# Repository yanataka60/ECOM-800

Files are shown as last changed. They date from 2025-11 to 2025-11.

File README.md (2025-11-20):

# ECOM-800

　トランジスタ技術 1977年10月号から1978年1月号にかけて連載されていた「マイコンピュータをつくろう(SC/MP編)」のECOM-800の基板を起こしました。

## 回路図
　KiCadフォルダ内のECOM-800.pdfを参照してください。

　掲載されている回路から以下の変更をしています。

　・ワンボードとするためにロータリースイッチをスライドスイッチに変更しています。

　・81LS95を74LS244に変更しています。

　・SRAMを6264としています。

　・SRAMのバッテリーバックアップを付加しました。

[回路図](https://github.com/yanataka60/ECOM-800/blob/main/Kicad/ECOM-800.pdf)
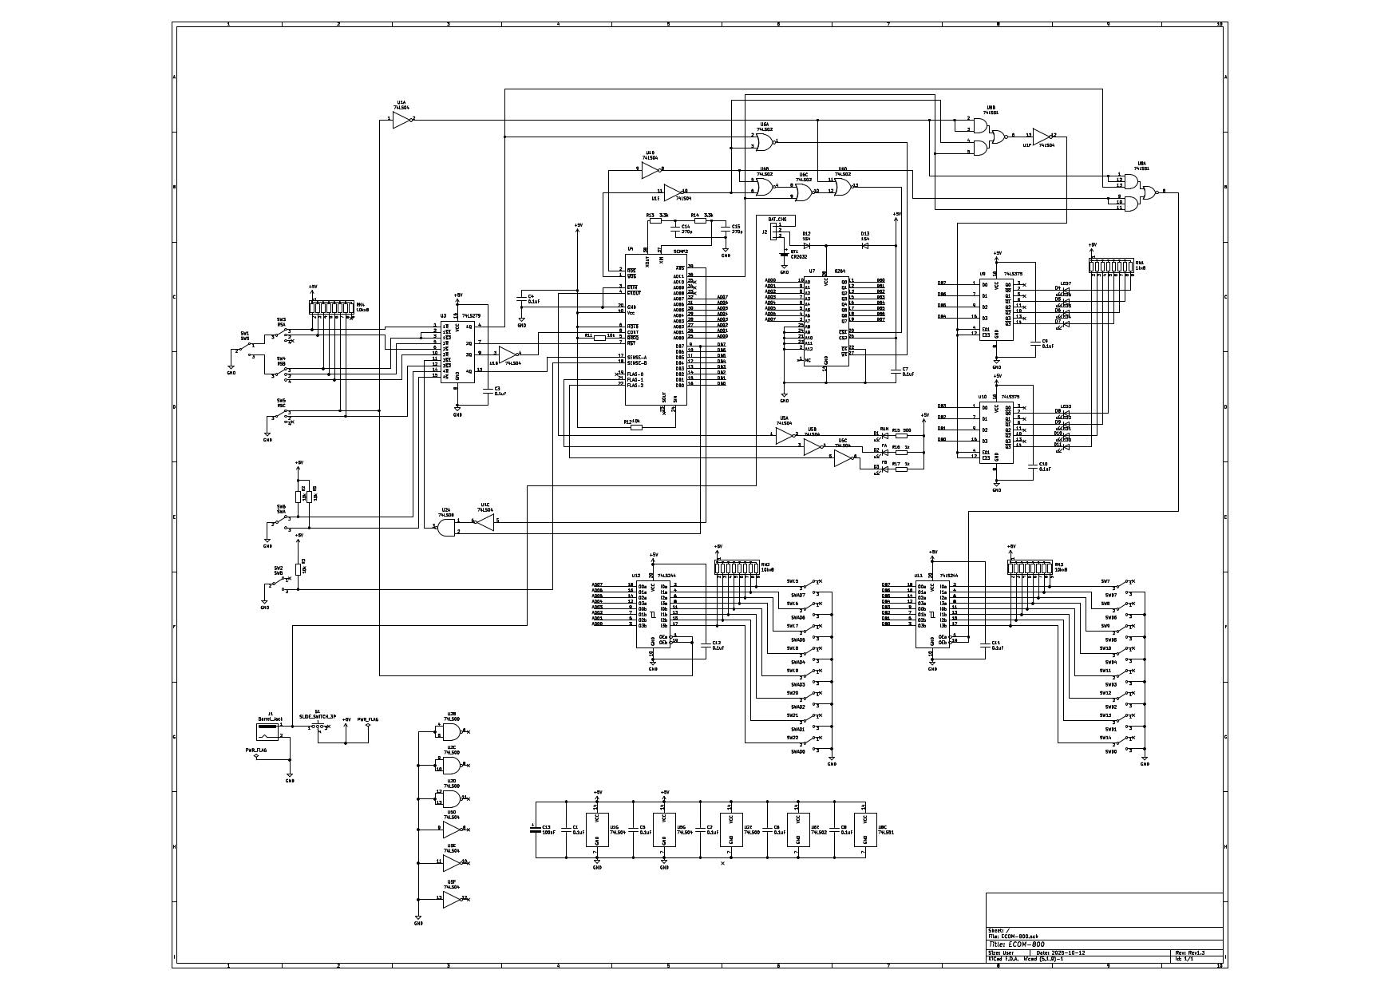
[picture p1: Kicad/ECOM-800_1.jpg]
回路図


## 部品表
|番号|品名|数量|備考|
| --- | --- | --- | --- |
|C1-C12|積層セラミックコンデンサ 0.1uF|12||
|C13|電解コンデンサ 100uF|1||
|C14,C15|積層セラミックコンデンサ 270pF|2||
|D1-D11|5mm赤色LED|11|秋月電子通商 OSDR5113Aなど|
|D12-D13|ダイオード 1S4|2|秋月電子通商など|
|J1|DCジャック|1|秋月電子通商 MJ-179PHなど|
|J2|3Pスライドスイッチ又は1x3ピンヘッダとジャンパーピン|1|秋月電子通商 SS12D01G4又はPH-1X3SG,MJ-254-6BK等|
|R2,R3,R5,R11,R12|カーボン抵抗 10k|5||
|R13,R14|カーボン抵抗 3.3k|2||
|R15|カーボン抵抗 500Ω|1||
|R16,R17|カーボン抵抗 1k|2||
|RN1|集合抵抗 1k×8|1|秋月電子通商 RKC8BD102Jなど|
|RN2-RN4|集合抵抗 10k×8|3|秋月電子通商 RKC8BD103Jなど|
|S1|3Pスライドスイッチ|1|秋月電子通商 SS12D01G4など|
|SW1,SW6|3Pプッシュスイッチ|2|共立エレショップ MS-650B-C-P-N/Rなど|
|SW3-SW5|1回路3接点 小型スライドスイッチ|3|Amazon,楽天市場,aitendo SS13D07など|
|SW2,SW7-SW22|3Pトグルスイッチ|17|共立エレショップ 2MS1-T1-B1-M2-QNなど|
|U1,U5|74LS04|2|樫木総業等|
|U2|74LS00|1|樫木総業等|
|U3|74LS279|1|樫木総業等|
|U4|SC/MPⅡ(INS8060)|1|ebay等(不良品多し)|
|U6|74LS02|1|樫木総業等|
|U7|SRAM 6264|1|若松通商等|
|U8|74LS51|1|樫木総業等|
|U9,U10|74LS375|2|樫木総業等|
|U11,U12|74LS244|2|樫木総業等|
|BT1|ボタン電池基板取付用ホルダー CR2032用(縦型)|1|秋月電子通商 CH243-2032LFなど|

## 組み立ての注意点
　SW1の取付向きに注意してください。押されていない状態で上側がONとなるようにつけます。

## ボードの完成写真
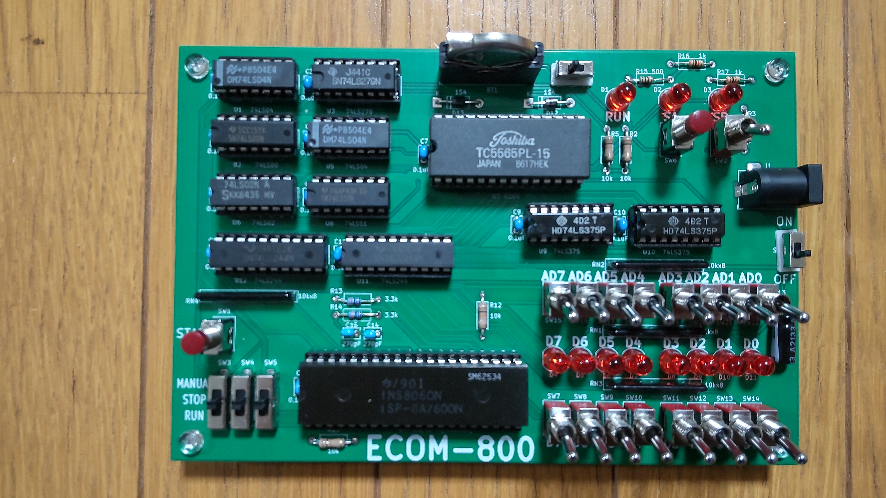
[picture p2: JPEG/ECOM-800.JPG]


## バッテリーバックアップ
　J2のEXT側でCR2032でのバックアップになり、IN側で電源ラインでのバックアップになります。

　CR2032を使わなくても電源に電池等を使ってIN側しておけば電池を外さない限りバックアップされます。

　なお、ECOM-800の回路の特性として電源スイッチがONになった時にデータ・スイッチ(D0～D7)の状態がメモリ0000hに書き込まれてしまうようです。(アドレススイッチの状態に関係なく、0000hに書き込まれます)

　0000hに意図して書き込んだ内容が勝手に書き換わってしまいますが、SC/MPⅡで0000hは実行されませんので書き換わってしまっても影響はありません。

## ECOM-800掲載個所
　トランジスタ技術

　　 1977年10月号 P238～P247

　　 1977年11月号 P266～P275

　　 1977年12月号 P262～P271

　　 1978年 1月号 P267～P277

## SAMPLEプログラム
　記事に掲載されている回転プログラムを発展させ、ナイトライダー風にしてみました。

　sampleフォルダ中のsample.lst又はsample.binを参照して入力してください。

## 利用上の注意
　KiCADデータおよびガーバーデータはCC BY-SA 4.0 (Copyright (C) 2024 Kazuhiro Ouchi)です。  

## 謝辞
　トグルスイッチ、プッシュスイッチのKiCADデータは、かんぱぱ様の「COSMAC Toy Computer Version 2」を使わせていただきました。

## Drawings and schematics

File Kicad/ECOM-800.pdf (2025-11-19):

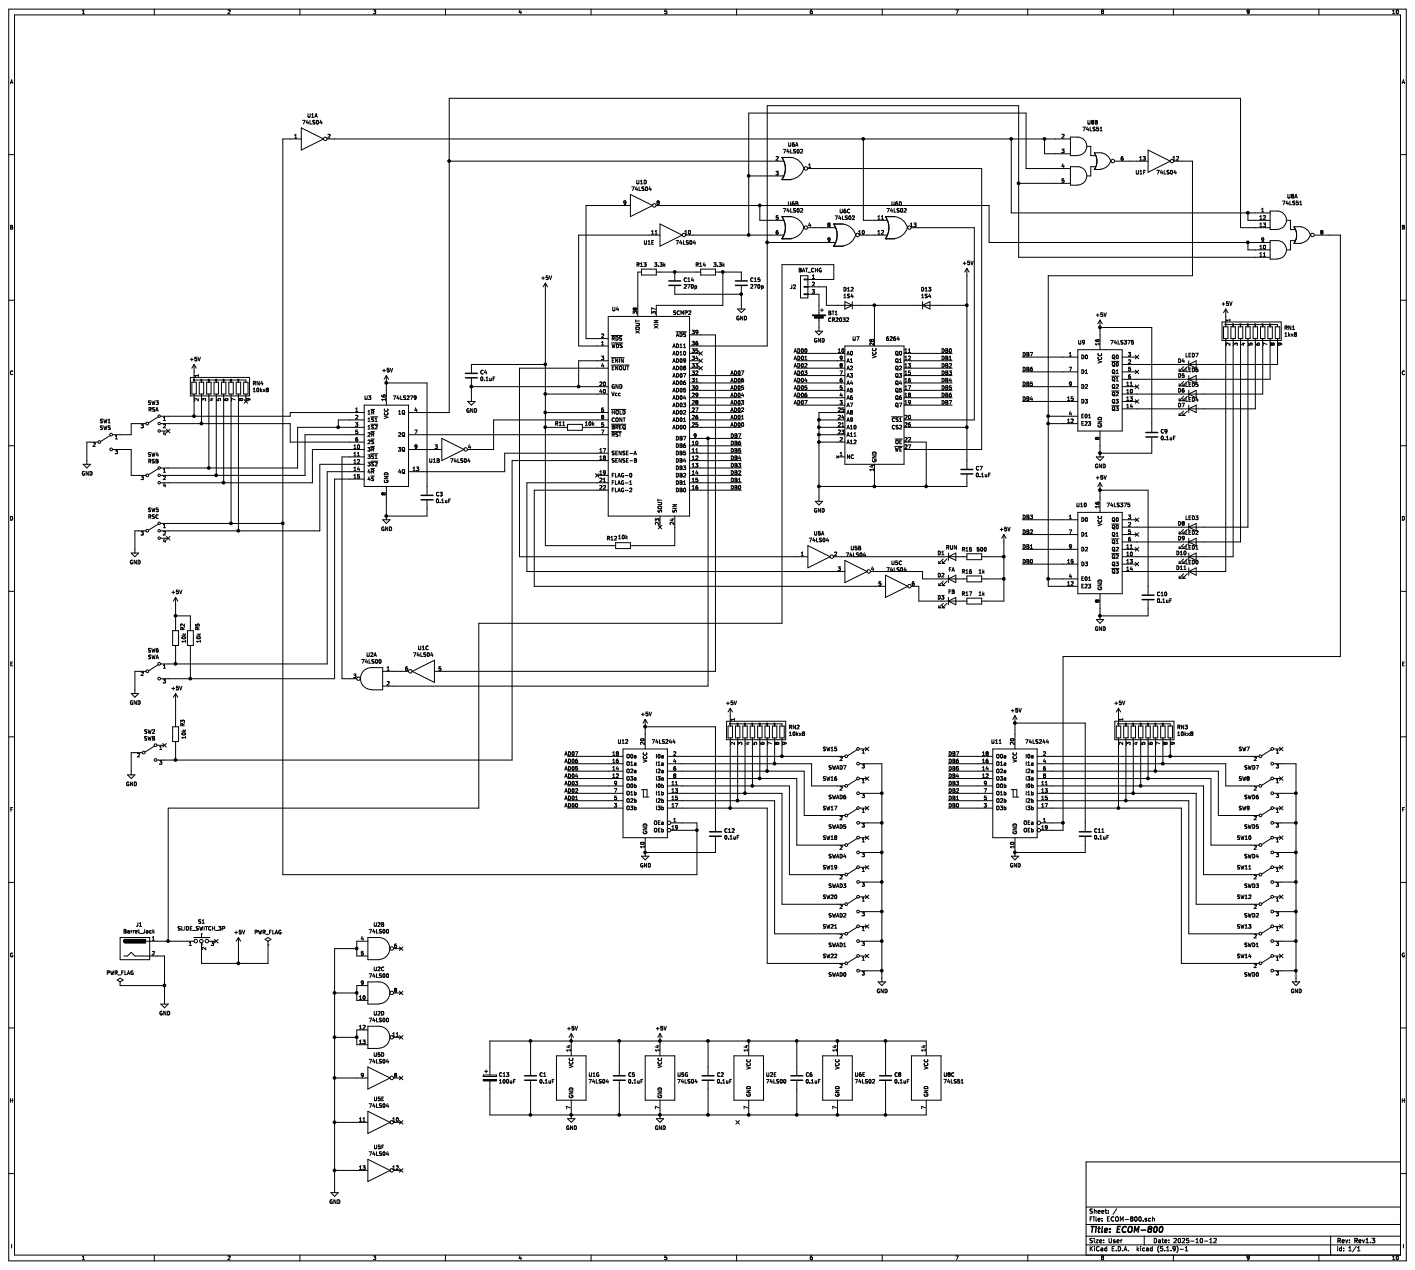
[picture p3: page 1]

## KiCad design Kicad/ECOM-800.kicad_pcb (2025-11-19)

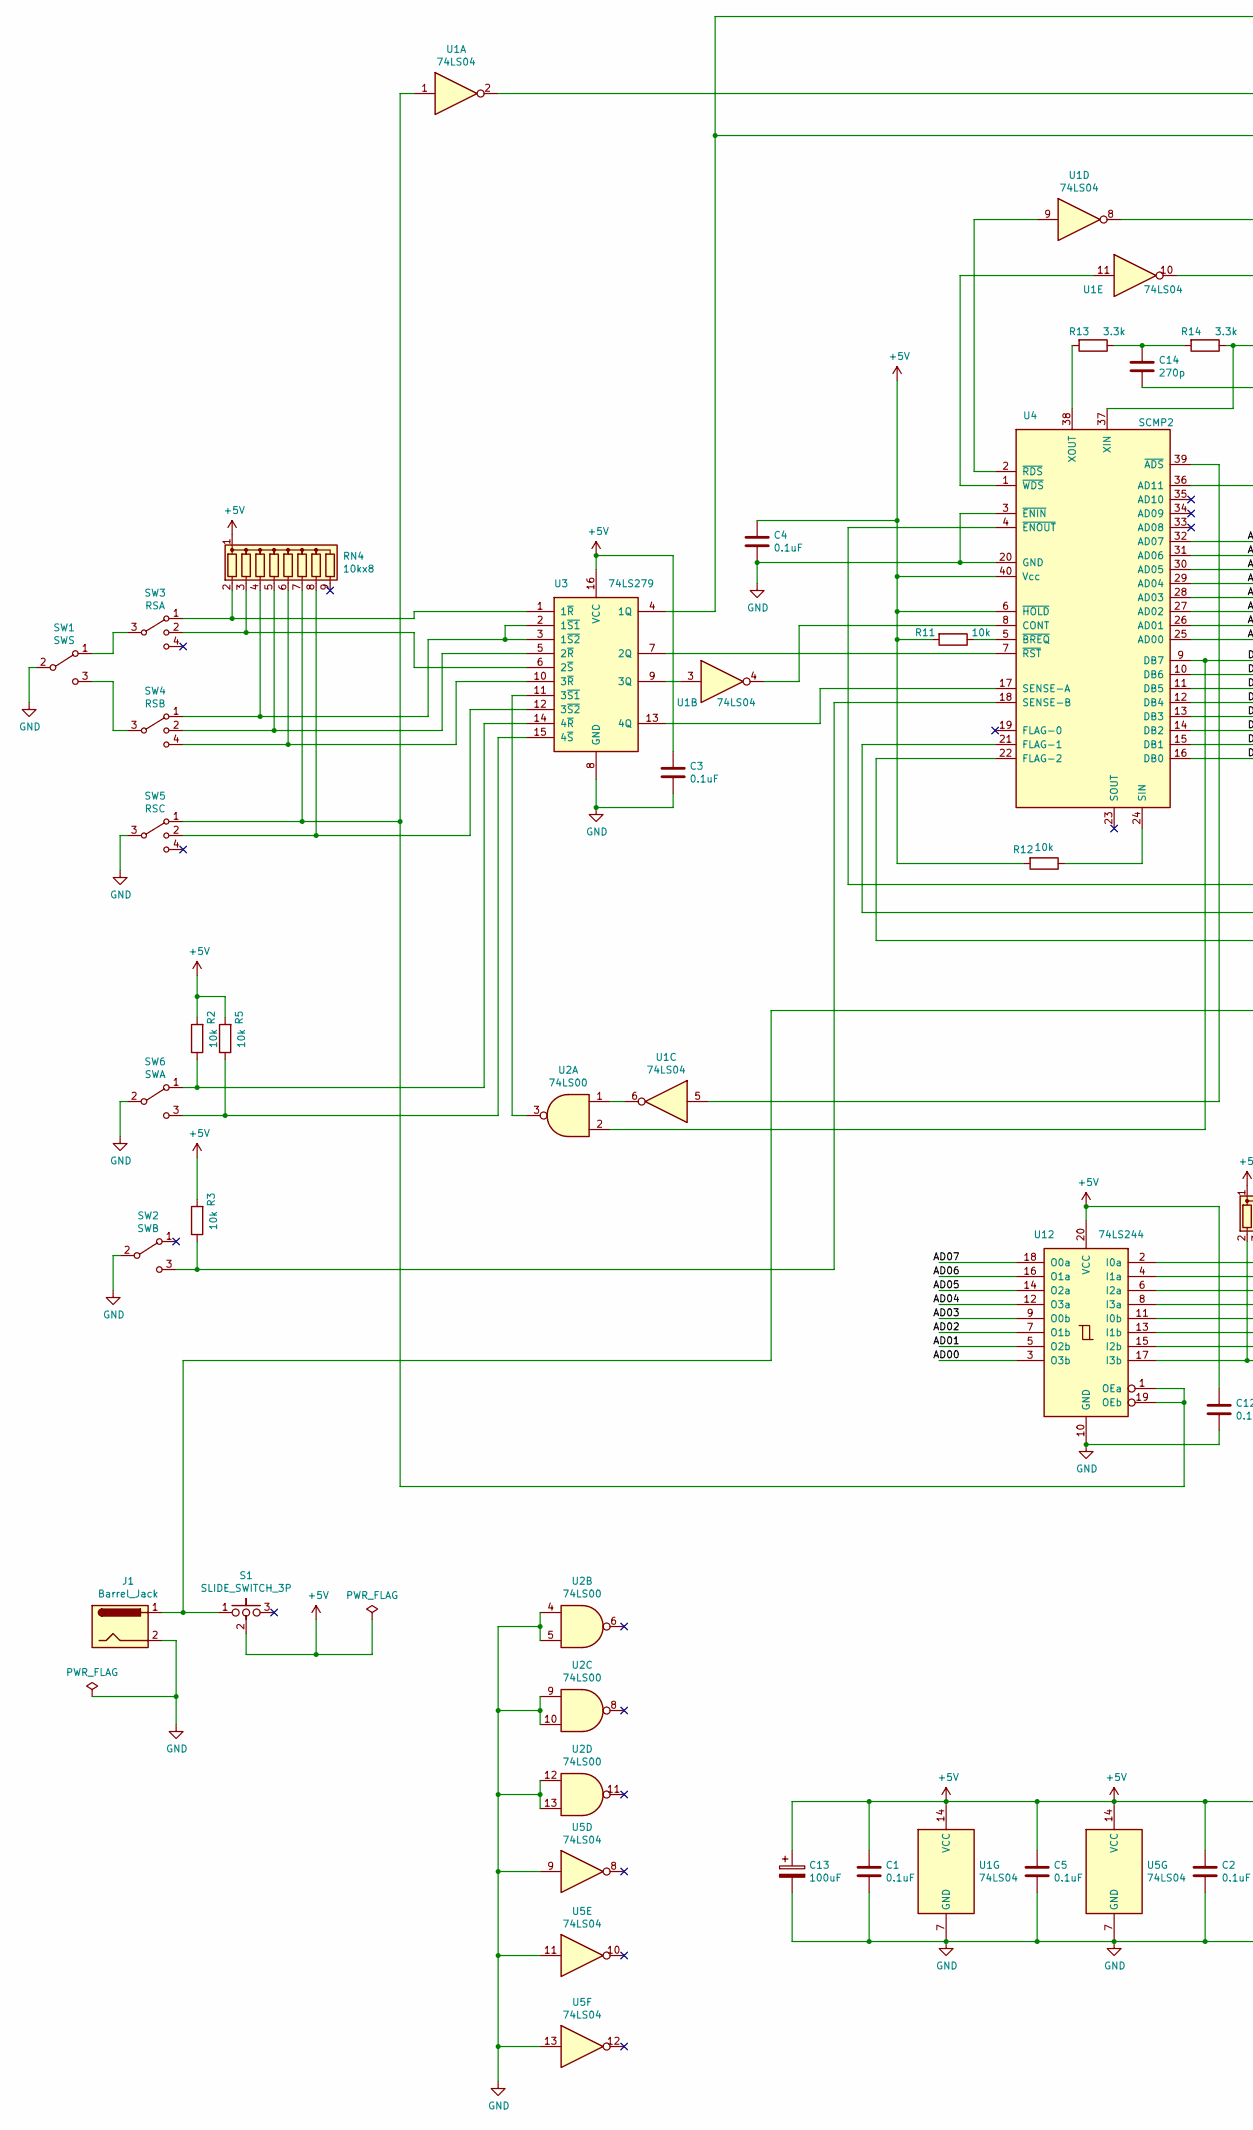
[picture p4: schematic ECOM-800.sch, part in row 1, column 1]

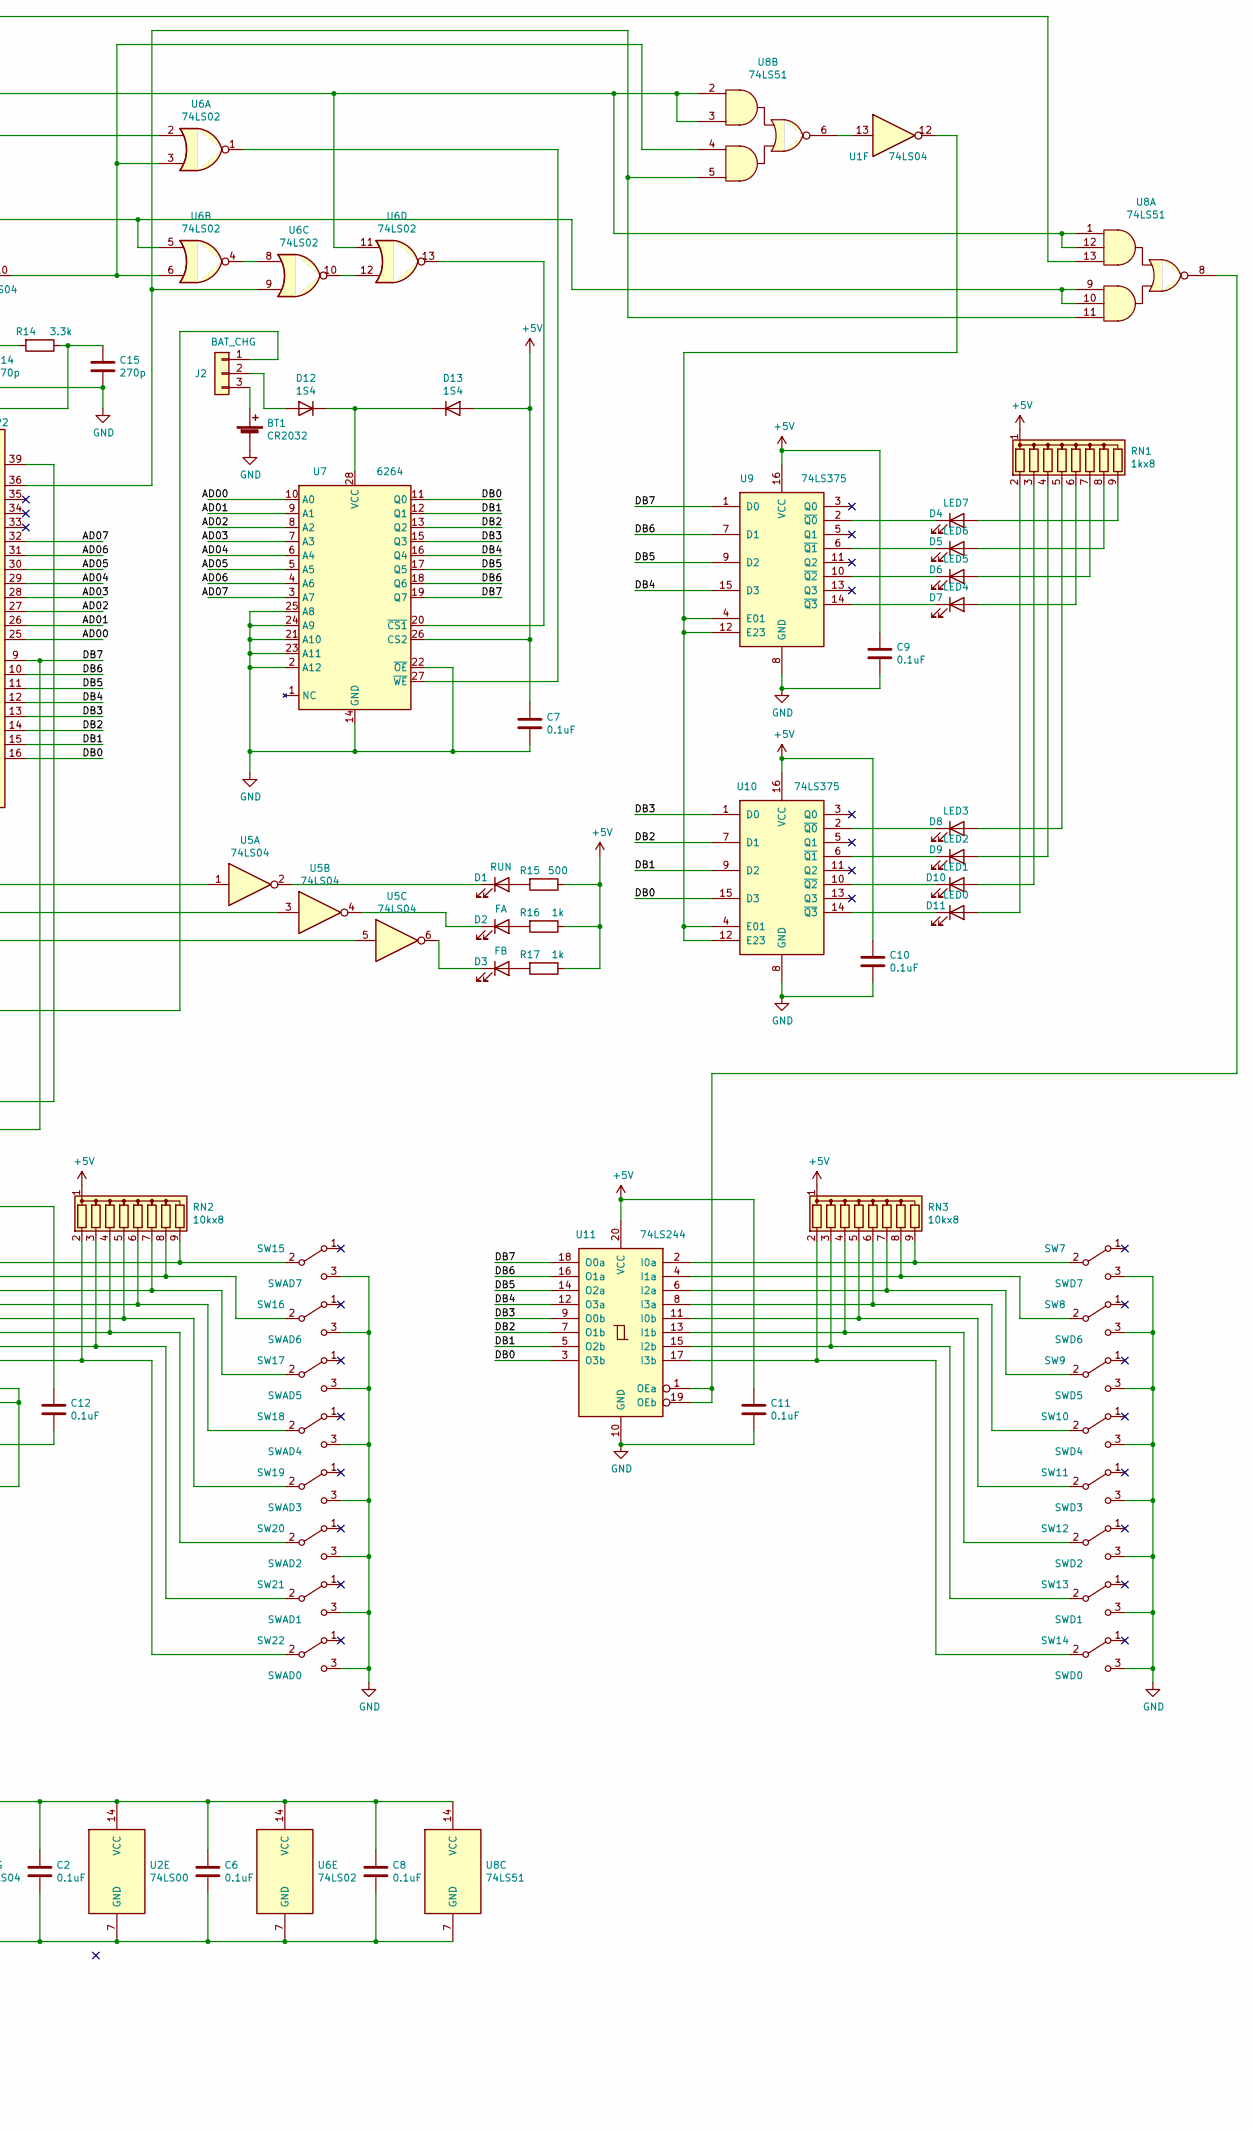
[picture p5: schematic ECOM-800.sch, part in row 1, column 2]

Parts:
BT1: CR2032; Battery_CR2032
C1, C2, C3, C4, C5, C6, C7, C8, C9, C10, C11, C12: 0.1uF; C_Rect_L4.0mm_W2.5mm_P2.50mm
C13: 100uF; CP_Radial_D5.0mm_P2.50mm
C14, C15: 270p; C_Rect_L4.0mm_W2.5mm_P2.50mm
D1: RUN; LED_D5.0mm
D2: FA; LED_D5.0mm
D3: FB; LED_D5.0mm
D4: LED7; LED_D5.0mm
D5: LED6; LED_D5.0mm
D6: LED5; LED_D5.0mm
D7: LED4; LED_D5.0mm
D8: LED3; LED_D5.0mm
D9: LED2; LED_D5.0mm
D10: LED1; LED_D5.0mm
D11: LED0; LED_D5.0mm
D12, D13: 1S4; D_DO-41_SOD81_P10.16mm_Horizontal
J1: Barrel_Jack; BarrelJack_Horizontal
J2: BAT_CHG; PinHeader_1x03_P2.54mm_Vertical
R2, R3, R5, R11, R12: 10k; R_Axial_DIN0207_L6.3mm_D2.5mm_P10.16mm_Horizontal
R13, R14: 3.3k; R_Axial_DIN0207_L6.3mm_D2.5mm_P10.16mm_Horizontal
R15: 500; R_Axial_DIN0207_L6.3mm_D2.5mm_P10.16mm_Horizontal
R16, R17: 1k; R_Axial_DIN0207_L6.3mm_D2.5mm_P10.16mm_Horizontal
RN1: 1kx8; R_Array_SIP9
RN2, RN3, RN4: 10kx8; R_Array_SIP9
S1: SLIDE_SWITCH_3P; PinHeader_1x03_P2.54mm_Vertical
SW1: SWS; SW_Toggle_P2.54mm_Vertical
SW2: SWB; SW_Toggle_P2.54mm_Vertical
SW3: RSA; Slide_Switch_1x3
SW4: RSB; Slide_Switch_1x3
SW5: RSC; Slide_Switch_1x3
SW6: SWA; SW_Toggle_P2.54mm_Vertical
SW7: SWD7; SW_Toggle_P2.54mm_Vertical
SW8: SWD6; SW_Toggle_P2.54mm_Vertical
SW9: SWD5; SW_Toggle_P2.54mm_Vertical
SW10: SWD4; SW_Toggle_P2.54mm_Vertical
SW11: SWD3; SW_Toggle_P2.54mm_Vertical
SW12: SWD2; SW_Toggle_P2.54mm_Vertical
SW13: SWD1; SW_Toggle_P2.54mm_Vertical
SW14: SWD0; SW_Toggle_P2.54mm_Vertical
SW15: SWAD7; SW_Toggle_P2.54mm_Vertical
SW16: SWAD6; SW_Toggle_P2.54mm_Vertical
SW17: SWAD5; SW_Toggle_P2.54mm_Vertical
SW18: SWAD4; SW_Toggle_P2.54mm_Vertical
SW19: SWAD3; SW_Toggle_P2.54mm_Vertical
SW20: SWAD2; SW_Toggle_P2.54mm_Vertical
SW21: SWAD1; SW_Toggle_P2.54mm_Vertical
SW22: SWAD0; SW_Toggle_P2.54mm_Vertical
U1, U5: 74LS04; DIP-14_W7.62mm_LongPads
U2: 74LS00; DIP-14_W7.62mm_LongPads
U3: 74LS279; DIP-16_W7.62mm_LongPads
U4: SCMP2; DIP-40_W15.24mm_LongPads
U6: 74LS02; DIP-14_W7.62mm_LongPads
U7: 6264; DIP-28_W15.24mm_LongPads
U8: 74LS51; DIP-14_W7.62mm_LongPads
U9, U10: 74LS375; DIP-16_W7.62mm_LongPads
U11, U12: 74LS244; DIP-20_W7.62mm_LongPads

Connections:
+5V: C1.1, C2.1, C3.1, C4.1, C5.1, C6.1, C7.1, C8.1, C9.1, C10.1, C11.1, C12.1, C13.1, D13.2 (A), R2.2, R3.2, R5.2, R11.2, R12.2, R15.1, R16.1, R17.1, RN1.1 (common), RN2.1 (common), RN3.1 (common), RN4.1 (common), S1.2, U1.14 (VCC), U2.14 (VCC), U3.16 (VCC), U4.6 (~HOLD), U4.40 (Vcc), U5.14 (VCC), U6.14 (VCC), U7.26 (CS2), U8.14 (VCC), U9.16 (VCC), U10.16 (VCC), U11.20 (VCC), U12.20 (VCC)
/AD00: U4.25 (AD00), U7.10 (A0), U12.3 (O3b)
/AD01: U4.26 (AD01), U7.9 (A1), U12.5 (O2b)
/AD02: U4.27 (AD02), U7.8 (A2), U12.7 (O1b)
/AD03: U4.28 (AD03), U7.7 (A3), U12.9 (O0b)
/AD04: U4.29 (AD04), U7.6 (A4), U12.12 (O3a)
/AD05: U4.30 (AD05), U7.5 (A5), U12.14 (O2a)
/AD06: U4.31 (AD06), U7.4 (A6), U12.16 (O1a)
/AD07: U4.32 (AD07), U7.3 (A7), U12.18 (O0a)
/DB0: U4.16 (DB0), U7.11 (Q0), U10.15 (D3), U11.3 (O3b)
/DB1: U4.15 (DB1), U7.12 (Q1), U10.9 (D2), U11.5 (O2b)
/DB2: U4.14 (DB2), U7.13 (Q2), U10.7 (D1), U11.7 (O1b)
/DB3: U4.13 (DB3), U7.15 (Q3), U10.1 (D0), U11.9 (O0b)
/DB4: U4.12 (DB4), U7.16 (Q4), U9.15 (D3), U11.12 (O3a)
/DB5: U4.11 (DB5), U7.17 (Q5), U9.9 (D2), U11.14 (O2a)
/DB6: U4.10 (DB6), U7.18 (Q6), U9.7 (D1), U11.16 (O1a)
/DB7: U2.2, U4.9 (DB7), U7.19 (Q7), U9.1 (D0), U11.18 (O0a)
GND: BT1.2 (-), C1.2, C2.2, C3.2, C4.2, C5.2, C6.2, C7.2, C8.2, C9.2, C10.2, C11.2, C12.2, C13.2, C14.2, C15.2, J1.2, SW1.2 (B), SW2.2 (B), SW5.3, SW6.2 (B), SW7.3 (C), SW8.3 (C), SW9.3 (C), SW10.3 (C), SW11.3 (C), SW12.3 (C), SW13.3 (C), SW14.3 (C), SW15.3 (C), SW16.3 (C), SW17.3 (C), SW18.3 (C), SW19.3 (C), SW20.3 (C), SW21.3 (C), SW22.3 (C), U1.7 (GND), U2.4, U2.5, U2.7 (GND), U2.9, U2.10, U2.12, U2.13, U3.8 (GND), U4.3 (~ENIN), U4.20 (GND), U5.7 (GND), U5.9, U5.11, U5.13, U6.7 (GND), U7.2 (A12), U7.14 (GND), U7.21 (A10), U7.22 (~OE), U7.23 (A11), U7.24 (A9), U7.25 (A8), U8.7 (GND), U9.8 (GND), U10.8 (GND), U11.10 (GND), U12.10 (GND)
unnamed: BT1.1 (+), J2.3
unnamed: C14.1, R13.1, R14.2
unnamed: C15.1, R14.1, U4.37 (XIN)
unnamed: D1.1 (K), U5.2
unnamed: D1.2 (A), R15.2
unnamed: D2.1 (K), U5.4
unnamed: D2.2 (A), R16.2
unnamed: D3.1 (K), U5.6
unnamed: D3.2 (A), R17.2
unnamed: D4.1 (K), U9.2 (~Q0)
unnamed: D4.2 (A), RN1.9 (R8)
unnamed: D5.1 (K), U9.6 (~Q1)
unnamed: D5.2 (A), RN1.8 (R7)
unnamed: D6.1 (K), U9.10 (~Q2)
unnamed: D6.2 (A), RN1.7 (R6)
unnamed: D7.1 (K), U9.14 (~Q3)
unnamed: D7.2 (A), RN1.6 (R5)
unnamed: D8.1 (K), U10.2 (~Q0)
unnamed: D8.2 (A), RN1.5 (R4)
unnamed: D9.1 (K), U10.6 (~Q1)
unnamed: D9.2 (A), RN1.4 (R3)
unnamed: D10.1 (K), U10.10 (~Q2)
unnamed: D10.2 (A), RN1.3 (R2)
unnamed: D11.1 (K), U10.14 (~Q3)
unnamed: D11.2 (A), RN1.2 (R1)
unnamed: D12.1 (K), D13.1 (K), U7.28 (VCC)
unnamed: D12.2 (A), J2.2
unnamed: J1.1, J2.1, S1.1
unnamed: R2.1, SW6.1 (A), U3.14 (4~R)
unnamed: R3.1, SW2.3 (C), U4.18 (SENSE-B)
unnamed: R5.1, SW6.3 (C), U3.15 (4~S)
unnamed: R11.1, U4.5 (~BREQ)
unnamed: R12.1, U4.24 (SIN)
unnamed: R13.2, U4.38 (XOUT)
unnamed: RN2.2 (R1), SW22.2 (B), U12.17 (I3b)
unnamed: RN2.3 (R2), SW21.2 (B), U12.15 (I2b)
unnamed: RN2.4 (R3), SW20.2 (B), U12.13 (I1b)
unnamed: RN2.5 (R4), SW19.2 (B), U12.11 (I0b)
unnamed: RN2.6 (R5), SW18.2 (B), U12.8 (I3a)
unnamed: RN2.7 (R6), SW17.2 (B), U12.6 (I2a)
unnamed: RN2.8 (R7), SW16.2 (B), U12.4 (I1a)
unnamed: RN2.9 (R8), SW15.2 (B), U12.2 (I0a)
unnamed: RN3.2 (R1), SW14.2 (B), U11.17 (I3b)
unnamed: RN3.3 (R2), SW13.2 (B), U11.15 (I2b)
unnamed: RN3.4 (R3), SW12.2 (B), U11.13 (I1b)
unnamed: RN3.5 (R4), SW11.2 (B), U11.11 (I0b)
unnamed: RN3.6 (R5), SW10.2 (B), U11.8 (I3a)
unnamed: RN3.7 (R6), SW9.2 (B), U11.6 (I2a)
unnamed: RN3.8 (R7), SW8.2 (B), U11.4 (I1a)
unnamed: RN3.9 (R8), SW7.2 (B), U11.2 (I0a)
unnamed: RN4.2 (R1), SW3.1, U3.1 (1~R)
unnamed: RN4.3 (R2), SW3.2, U3.6 (2~S)
unnamed: RN4.4 (R3), SW4.1, U3.2 (1~S1), U3.3 (1~S2)
unnamed: RN4.5 (R4), SW4.2, U3.5 (2~R)
unnamed: RN4.6 (R5), SW4.4, U3.10 (3~R)
unnamed: RN4.7 (R6), SW5.1, U1.1, U12.1 (OEa), U12.19 (OEb)
unnamed: RN4.8 (R7), SW5.2, U3.12 (3~S2)
unnamed: SW1.1 (A), SW3.3
unnamed: SW1.3 (C), SW4.3
unnamed: U1.2, U6.11, U8.1, U8.2, U8.3, U8.12
unnamed: U1.3, U3.9 (3Q)
unnamed: U1.4, U4.8 (CONT)
unnamed: U1.5, U4.39 (~ADS)
unnamed: U1.6, U2.1
unnamed: U1.8, U6.5, U8.9, U8.10
unnamed: U1.9, U4.2 (~RDS)
unnamed: U1.10, U6.3, U6.6, U8.4
unnamed: U1.11, U4.1 (~WDS)
unnamed: U1.12, U9.4 (E01), U9.12 (E23), U10.4 (E01), U10.12 (E23)
unnamed: U1.13, U8.6
unnamed: U2.3, U3.11 (3~S1)
unnamed: U3.4 (1Q), U6.2, U8.13
unnamed: U3.7 (2Q), U4.7 (~RST)
unnamed: U3.13 (4Q), U4.17 (SENSE-A)
unnamed: U4.4 (~ENOUT), U5.1
unnamed: U4.21 (FLAG-1), U5.3
unnamed: U4.22 (FLAG-2), U5.5
unnamed: U4.36 (AD11), U6.9, U8.5, U8.11
unnamed: U6.1, U7.27 (~WE)
unnamed: U6.4, U6.8
unnamed: U6.10, U6.12
unnamed: U6.13, U7.20 (~CS1)
unnamed: U8.8, U11.1 (OEa), U11.19 (OEb)

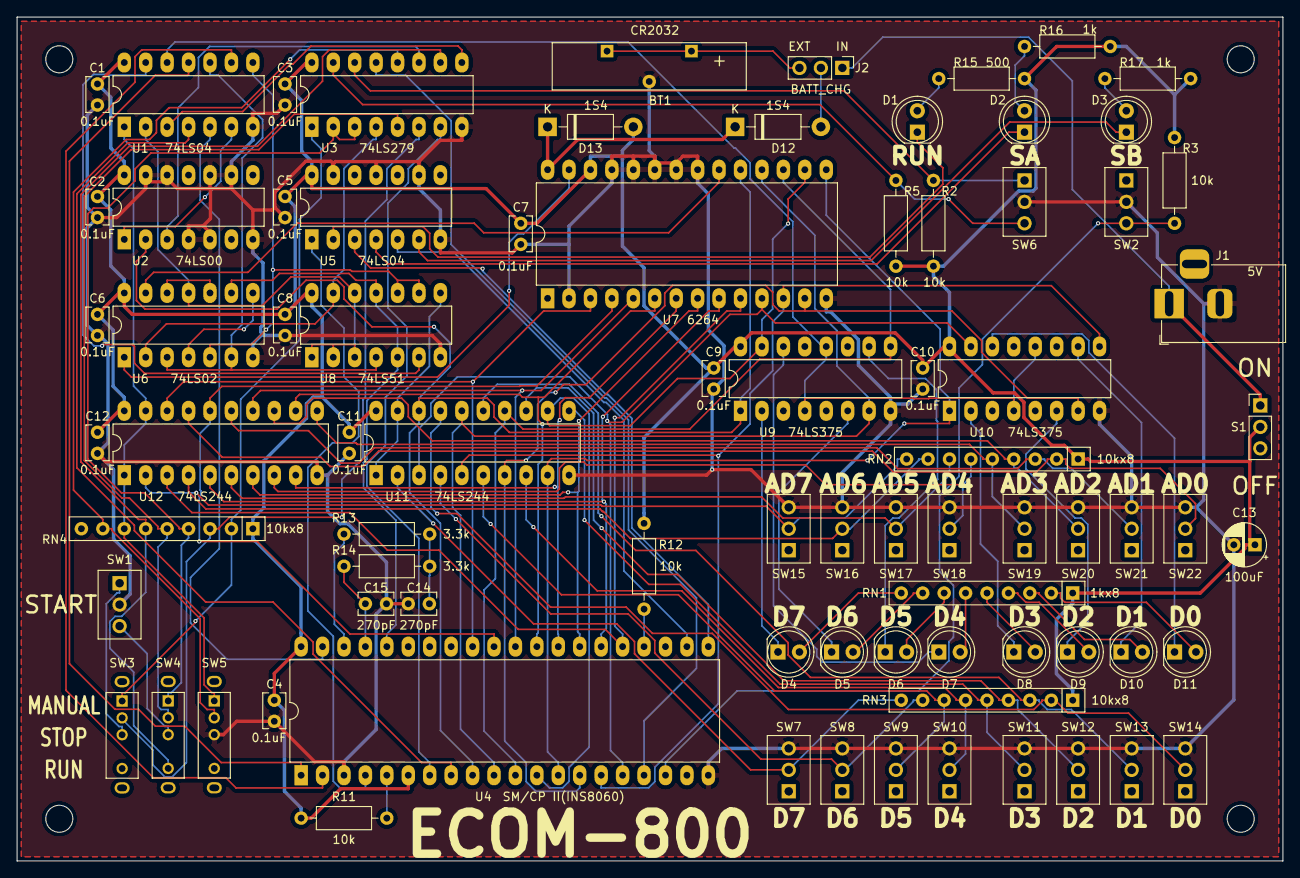
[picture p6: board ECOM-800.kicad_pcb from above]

Board: 2 copper layers, 150.0 x 100.0 mm, 84 parts (0 on the bottom side), 101 nets.

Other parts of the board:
MH1, MH2, MH3, MH4: MountingHole_3.2mm_M3
